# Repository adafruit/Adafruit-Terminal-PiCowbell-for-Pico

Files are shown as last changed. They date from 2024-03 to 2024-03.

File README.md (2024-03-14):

## Adafruit Terminal PiCowbell for Pico - Reset Button & STEMMA QT PCB

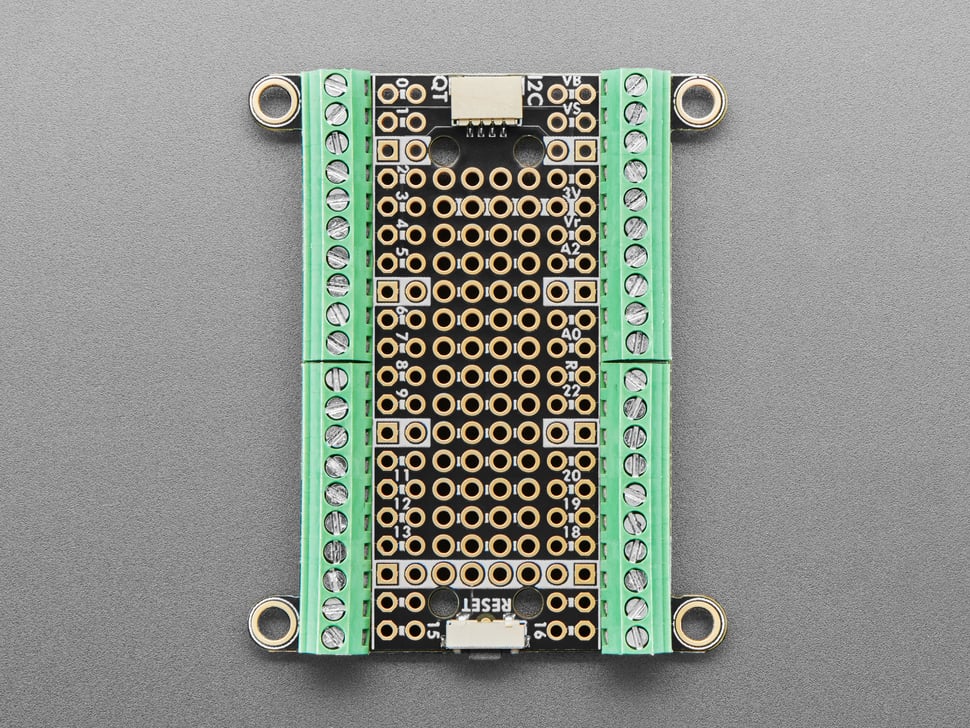
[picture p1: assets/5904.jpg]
<a href="http://www.adafruit.com/products/5904"><br/>
Click here to purchase one from the Adafruit shop</a>

PCB files for the Adafruit Terminal PiCowbell for Pico - Reset Button & STEMMA QT. 

Format is EagleCAD schematic and board layout
* https://www.adafruit.com/product/5904

### Description

Ding dong! Hear that? It's the PiCowbell ringing, letting you know that the new Adafruit Terminal PiCowbell is finally in stock and ready to assist your Raspberry Pi Pico and Pico W project with handy hardware and practical prototyping with screw terminal blocks for each and every pin.

This board is ideal for when you want quick access to connect solid or stranded core wires to any of the GPIO pads on the Pico. We use four 10-pin 2.54" pitch screw terminal blocks that can fit 18~26 AWG solid or stranded core wires. Note that we really connect every pin 1-to-1 so there will be plenty of ground connects!

Please Note! To keep things flexible, this PiCowbell does not come with socket or pin headers, even though we have some example photos with not-included socket headers installed. There are many possible configurations, and we stock various headers depending on how you want to solder and attach them. This is especially true if you want the Pico on top so that the BOOTSEL button and LED are accessible.

Use the Pico Stacking Headers if you want to plug into a breadboard or other accessory with sockets.
Use the Pico Socket Headers if you want to plug directly in and have a nice, solid connection without any poking-out bits.
Use the Short Socket Headers for a very slim but pluggable design, note that you'll want to trim down the Pico's headers or use the short plug headers on the Pico to have a skinny sandwich.
Solder the PCB directly to the Pico headers - of course, this is very compact and inexpensive, but you won't be able to remove the PiCowbell.
The Terminal PiCowbell provides you with:

* Screw Terminal blocks for each matching pad on the Pico or Pico W: 40 total pins, 40 total blocks
* Right angle reset button that sticks out the end
* Right angle JST SH connector for I2C / Stemma QT / Qwiic connection. Or can use it for plain GPIO wiring if you don't have any I2C devices to attach. Provides 3V, GND, IO4 (SDA), and IO5 (SCL)
* There is an extra set of 4 breakout holes next to the JST SH in case you want more I2C connections or want to re-assign the I2C port.
* 15 rows of 8-hole connected strips in the center area. You can cut the traces between the holes, but they're intended to be treated like a mini-mini breadboard
* Every pad on the Pico has a duplicate hole pad next to it for solder-jumpering
* The ground pads have white silkscreen rectangles to easily identify, plus one long ground strip near the reset button
* One long strip of connected holes for 3.3V power
* Gold-plated pads for easy soldering

We do not have I2C pullups on the board, but your Qwiic/QT breakout board or accessory likely already has them onboard. If using the Philhower Arduino core, the Wire peripheral is already set up to use IO4 and IO5. If using CircuitPython or MicroPython, you'll need to let the code know to look at 4+5 for SDA+SCL pins.

### License

Adafruit invests time and resources providing this open source design, please support Adafruit and open-source hardware by purchasing products from [Adafruit](https://www.adafruit.com)!

Designed by Limor Fried/Ladyada for Adafruit Industries.

Creative Commons Attribution/Share-Alike, all text above must be included in any redistribution. 
See license.txt for additional details.

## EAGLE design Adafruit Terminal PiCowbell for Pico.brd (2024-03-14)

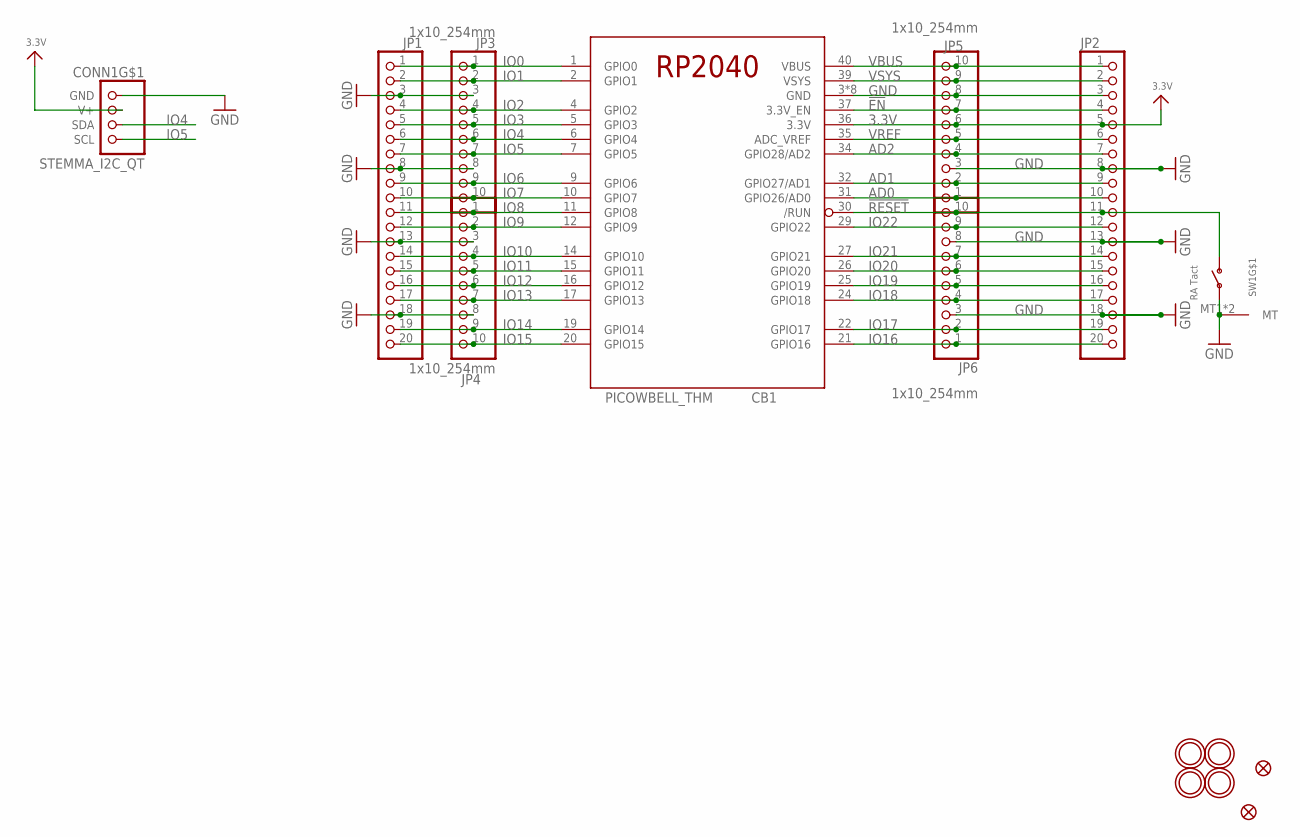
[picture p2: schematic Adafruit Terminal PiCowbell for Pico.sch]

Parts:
CB1: PICOWBELL_THM
CONN1: STEMMA_I2C_QT; JST_SH4
FID1, FID2: FIDUCIAL_1MM
JP1, JP2: HEADER-1X20_70MIL; 1X20_ROUND_70MIL
JP3, JP4, JP5, JP6: 1x10_254mm; 1X10_2.54MMTERMINAL
SW1: RA Tact; SPST_TACTILE_RA
U$5, U$7, U$8, U$9: MOUNTINGHOLE3.0THIN; MOUNTINGHOLE_3.0_PLATEDTHIN

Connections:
3.3V: CB1.36 (3.3V), CONN1.2 (V+), JP2.5, JP5.6
!EN: CB1.37 (3.3V_EN), JP2.4, JP5.7
!RESET: CB1.30 (/RUN), JP2.11, JP6.10, SW1.2 (S)
AD0: CB1.31 (GPIO26/AD0), JP2.10, JP5.1
AD1: CB1.32 (GPIO27/AD1), JP2.9, JP5.2
AD2: CB1.34 (GPIO28/AD2), JP2.7, JP5.4
GND: CB1.3 (GND), CB1.8 (GND), CB1.13 (GND), CB1.18 (GND), CB1.23 (GND), CB1.28 (GND), CB1.33 (GND), CB1.38 (GND), CONN1.1 (GND), JP1.3, JP1.8, JP1.13, JP1.18, JP2.3, JP2.8, JP2.13, JP2.18, JP3.3, JP3.8, JP4.3, JP4.8, JP5.3, JP5.8, JP6.3, JP6.8, SW1.1, SW1.MT1 (MT), SW1.MT2 (MT)
IO0: CB1.1 (GPIO0), JP1.1, JP3.1
IO1: CB1.2 (GPIO1), JP1.2, JP3.2
IO2: CB1.4 (GPIO2), JP1.4, JP3.4
IO3: CB1.5 (GPIO3), JP1.5, JP3.5
IO4: CB1.6 (GPIO4), CONN1.3 (SDA), JP1.6, JP3.6
IO5: CB1.7 (GPIO5), CONN1.4 (SCL), JP1.7, JP3.7
IO6: CB1.9 (GPIO6), JP1.9, JP3.9
IO7: CB1.10 (GPIO7), JP1.10, JP3.10
IO8: CB1.11 (GPIO8), JP1.11, JP4.1
IO9: CB1.12 (GPIO9), JP1.12, JP4.2
IO10: CB1.14 (GPIO10), JP1.14, JP4.4
IO11: CB1.15 (GPIO11), JP1.15, JP4.5
IO12: CB1.16 (GPIO12), JP1.16, JP4.6
IO13: CB1.17 (GPIO13), JP1.17, JP4.7
IO14: CB1.19 (GPIO14), JP1.19, JP4.9
IO15: CB1.20 (GPIO15), JP1.20, JP4.10
IO16: CB1.21 (GPIO16), JP2.20, JP6.1
IO17: CB1.22 (GPIO17), JP2.19, JP6.2
IO18: CB1.24 (GPIO18), JP2.17, JP6.4
IO19: CB1.25 (GPIO19), JP2.16, JP6.5
IO20: CB1.26 (GPIO20), JP2.15, JP6.6
IO21: CB1.27 (GPIO21), JP2.14, JP6.7
IO22: CB1.29 (GPIO22), JP2.12, JP6.9
VBUS: CB1.40 (VBUS), JP2.1, JP5.10
VREF: CB1.35 (ADC_VREF), JP2.6, JP5.5
VSYS: CB1.39 (VSYS), JP2.2, JP5.9

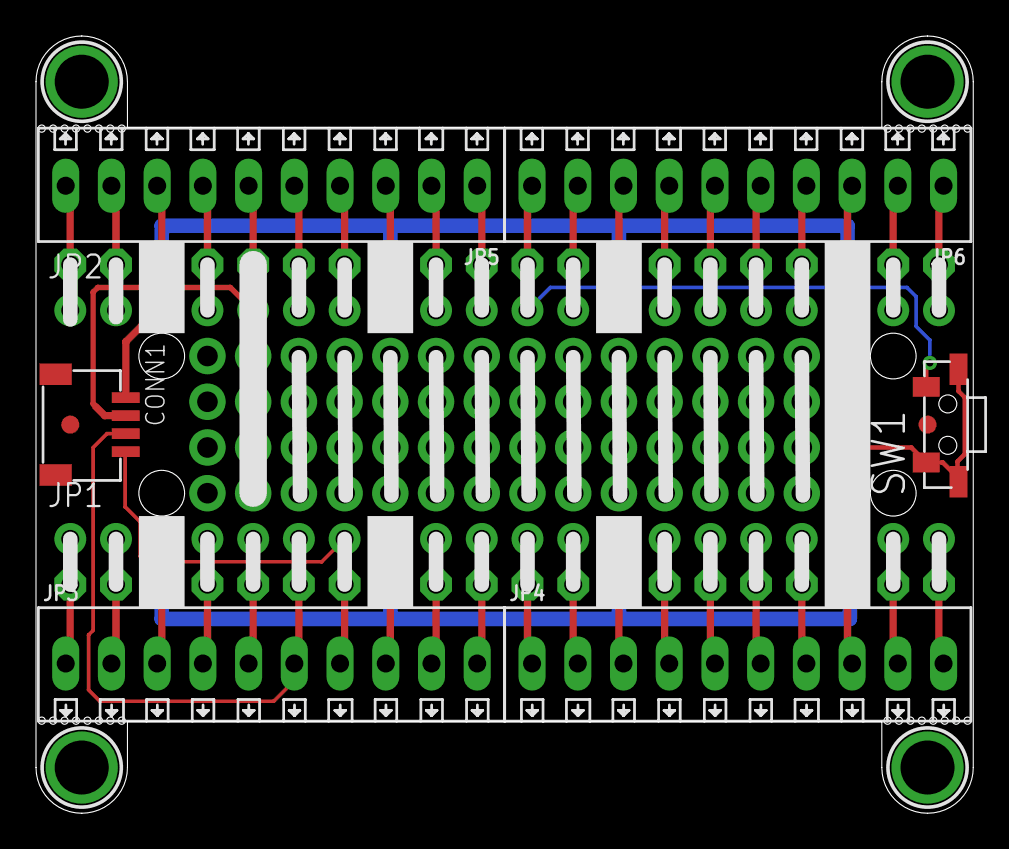
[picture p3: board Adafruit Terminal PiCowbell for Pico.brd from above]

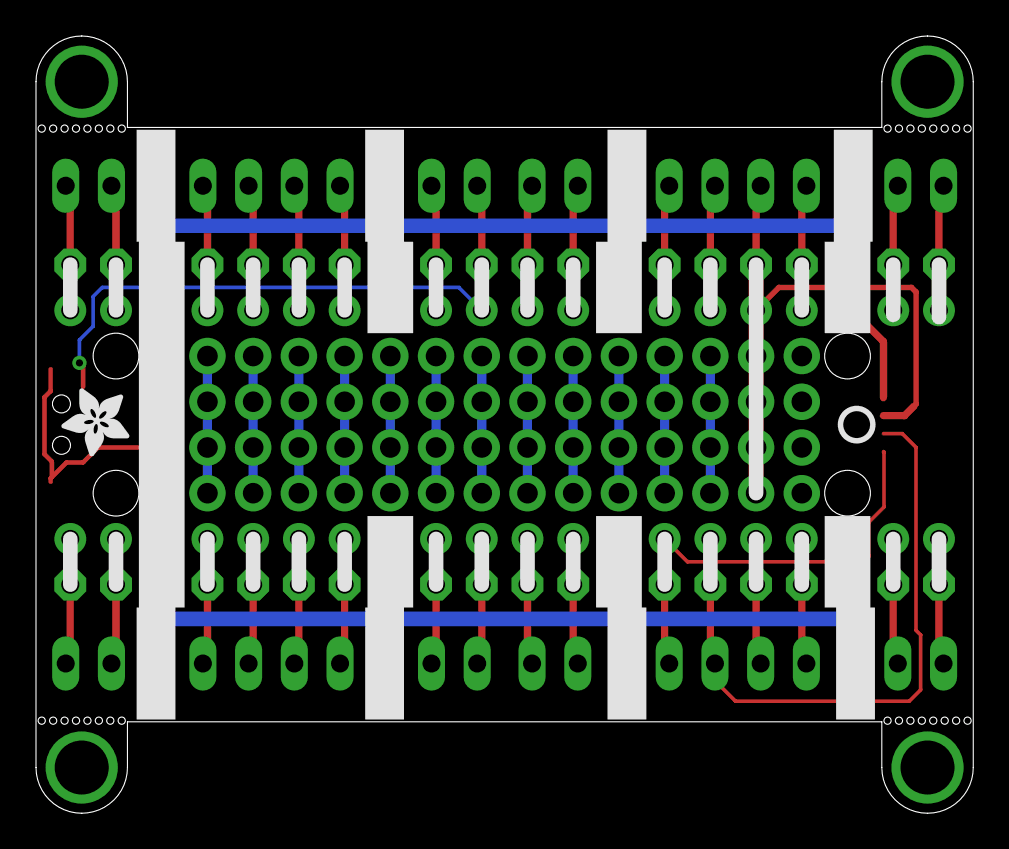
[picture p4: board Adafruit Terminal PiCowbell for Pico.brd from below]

Board: 2 copper layers, 52.1 x 43.2 mm, 105 parts (61 on the bottom side), 33 nets.

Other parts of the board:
E$1: ADAFRUIT_3.5MM
PLABEL0: PLABEL0
PLABEL1: PLABEL1
PLABEL2: PLABEL2
PLABEL3: PLABEL3
PLABEL4: PLABEL4
PLABEL5: PLABEL5
PLABEL6: PLABEL6
PLABEL7: PLABEL7
PLABEL8: PLABEL8
PLABEL9: PLABEL9
PLABEL10: PLABEL10
PLABEL11: PLABEL11
PLABEL12: PLABEL12
PLABEL13: PLABEL13
PLABEL14: PLABEL14
PLABEL15: PLABEL15
PLABEL17: PLABEL17
PLABEL19: PLABEL19
PLABEL20: PLABEL20
PLABEL21: PLABEL21
PLABEL22: PLABEL22
PLABEL23: PLABEL23
PLABEL24: PLABEL24
PLABEL25: PLABEL25
PLABEL26: PLABEL26
PLABEL27: PLABEL27
PLABEL28: PLABEL28
PLABEL29: PLABEL29
PLABEL30: PLABEL30
PLABEL35, PLABEL36: PLABEL36
PLABEL37, PLABEL68: PLABEL37
PLABEL38, PLABEL69: PLABEL38
PLABEL39, PLABEL70: PLABEL39
PLABEL40, PLABEL71: PLABEL40
PLABEL41, PLABEL72: PLABEL41
PLABEL42, PLABEL73: PLABEL42
PLABEL43, PLABEL74: PLABEL43
PLABEL44, PLABEL75: PLABEL44
PLABEL45, PLABEL76: PLABEL45
PLABEL46, PLABEL94: PLABEL46
PLABEL47, PLABEL93: PLABEL47
PLABEL48, PLABEL92: PLABEL48
PLABEL49, PLABEL88: PLABEL49
PLABEL50, PLABEL81: PLABEL50
PLABEL52, PLABEL82: PLABEL52
PLABEL54, PLABEL87: PLABEL54
PLABEL55, PLABEL86: PLABEL55
PLABEL56, PLABEL84: PLABEL56
PLABEL57, PLABEL77: PLABEL57
PLABEL58, PLABEL78: PLABEL58
PLABEL59, PLABEL85: PLABEL59
PLABEL60, PLABEL79: PLABEL60
PLABEL61, PLABEL89: PLABEL61
PLABEL62, PLABEL90: PLABEL62
PLABEL63, PLABEL91: PLABEL63
PLABEL64: PLABEL64
PLABEL65: PLABEL65
PLABEL66: PLABEL66
PLABEL67: PLABEL67
PLABEL80: PLABEL51
PLABEL83: PLABEL53
PLABEL688: PLABEL688
U$6: PCBFEAT-REV-040

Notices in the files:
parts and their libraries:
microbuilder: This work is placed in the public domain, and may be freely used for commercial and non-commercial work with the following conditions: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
